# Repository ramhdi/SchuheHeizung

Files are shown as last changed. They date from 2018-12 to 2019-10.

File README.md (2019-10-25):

# SchuheHeizung
DIY Thermostat - Applicable for shoe dryer, sous vide cooker, etc

## Arduino codes
- SchuheHeizung v1: first version, heating controlled by user via Blynk app, microcontroller using NodeMCU
- SchuheHeizung v2: offline heating control, uses OLED display and rotary encoder as user interface, microcontroller using Arduino Nano

## PCB files
- SH v1: first version, microcontroller using NodeMCU, controls DC fan and heater
- SH v2: microcontroller using Arduino Nano, controls AC fan and heater
- SH v3: microcontroller using NodeMCU, controls AC fan and heater

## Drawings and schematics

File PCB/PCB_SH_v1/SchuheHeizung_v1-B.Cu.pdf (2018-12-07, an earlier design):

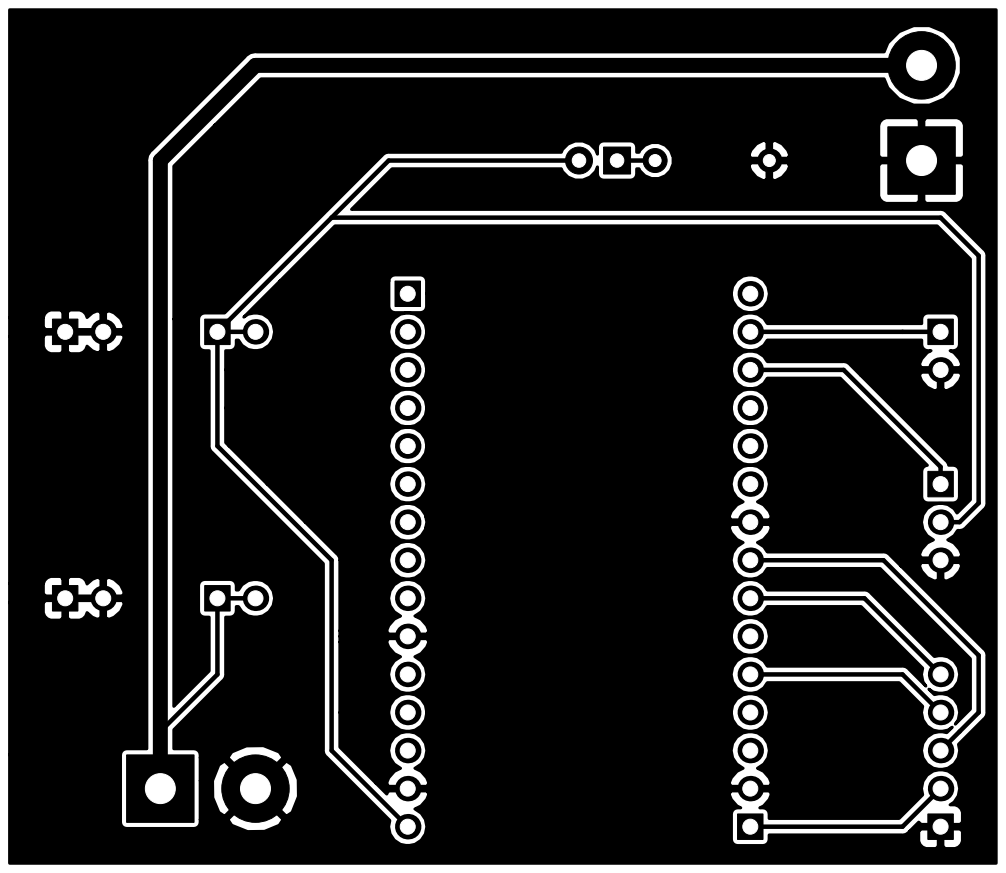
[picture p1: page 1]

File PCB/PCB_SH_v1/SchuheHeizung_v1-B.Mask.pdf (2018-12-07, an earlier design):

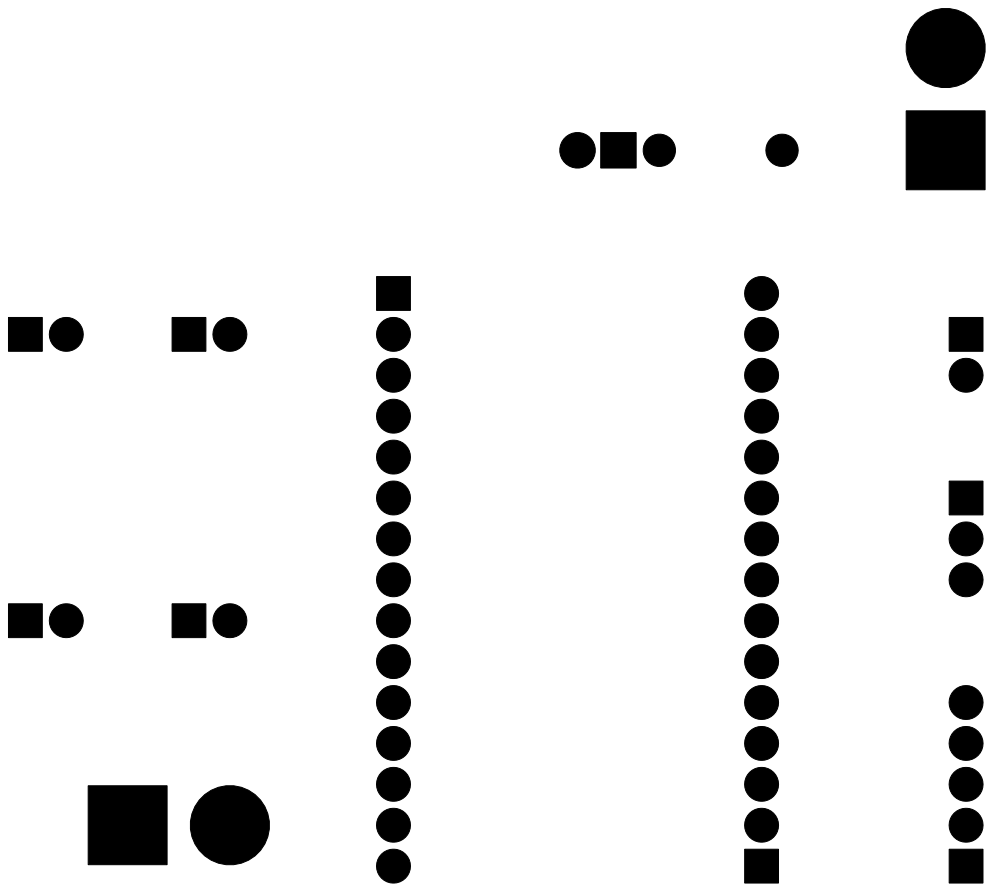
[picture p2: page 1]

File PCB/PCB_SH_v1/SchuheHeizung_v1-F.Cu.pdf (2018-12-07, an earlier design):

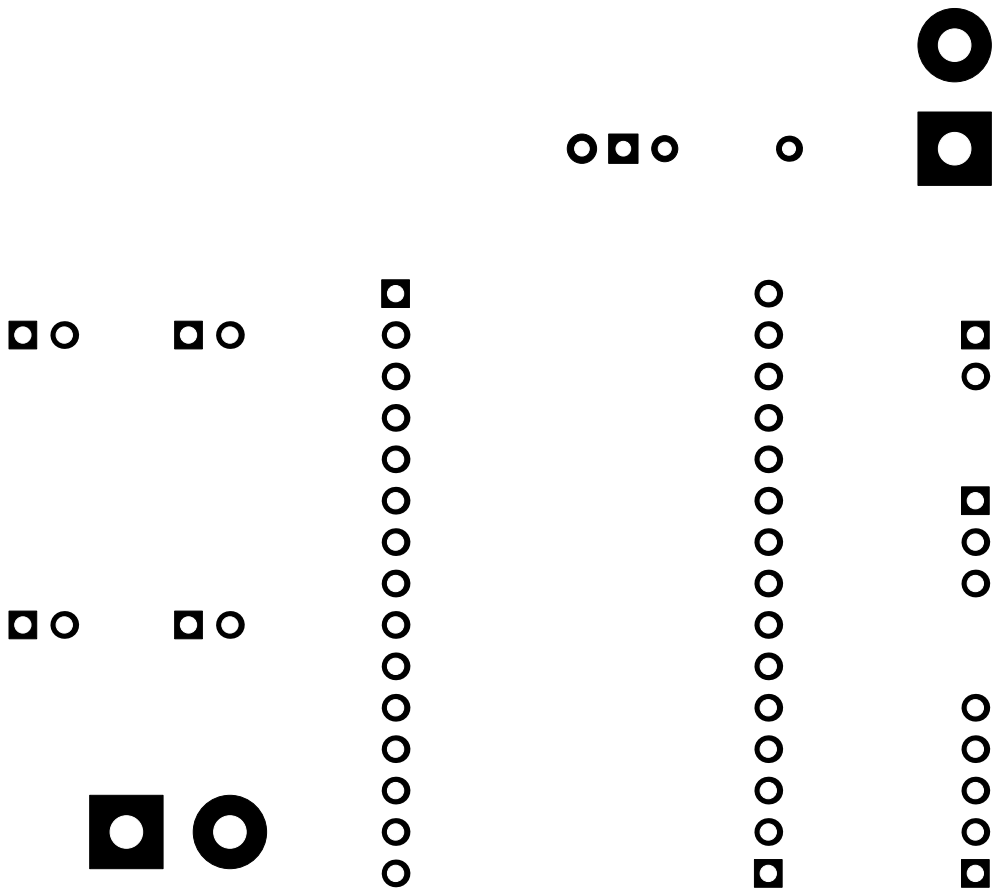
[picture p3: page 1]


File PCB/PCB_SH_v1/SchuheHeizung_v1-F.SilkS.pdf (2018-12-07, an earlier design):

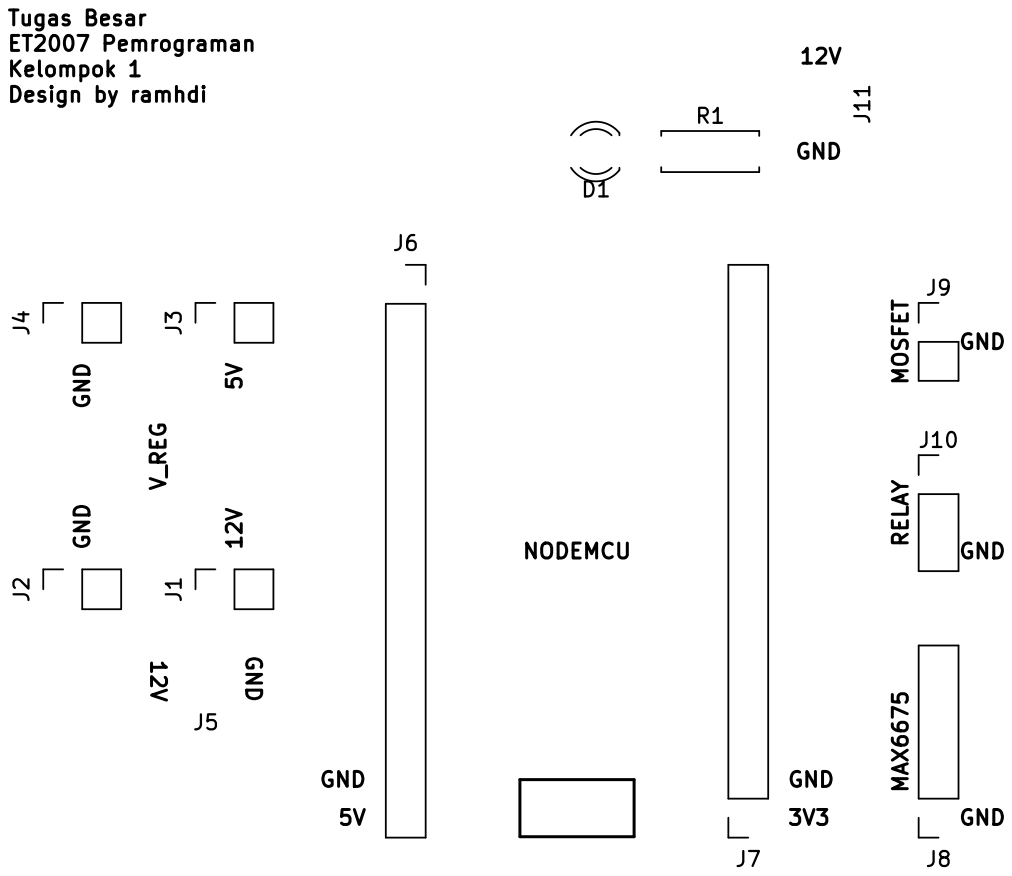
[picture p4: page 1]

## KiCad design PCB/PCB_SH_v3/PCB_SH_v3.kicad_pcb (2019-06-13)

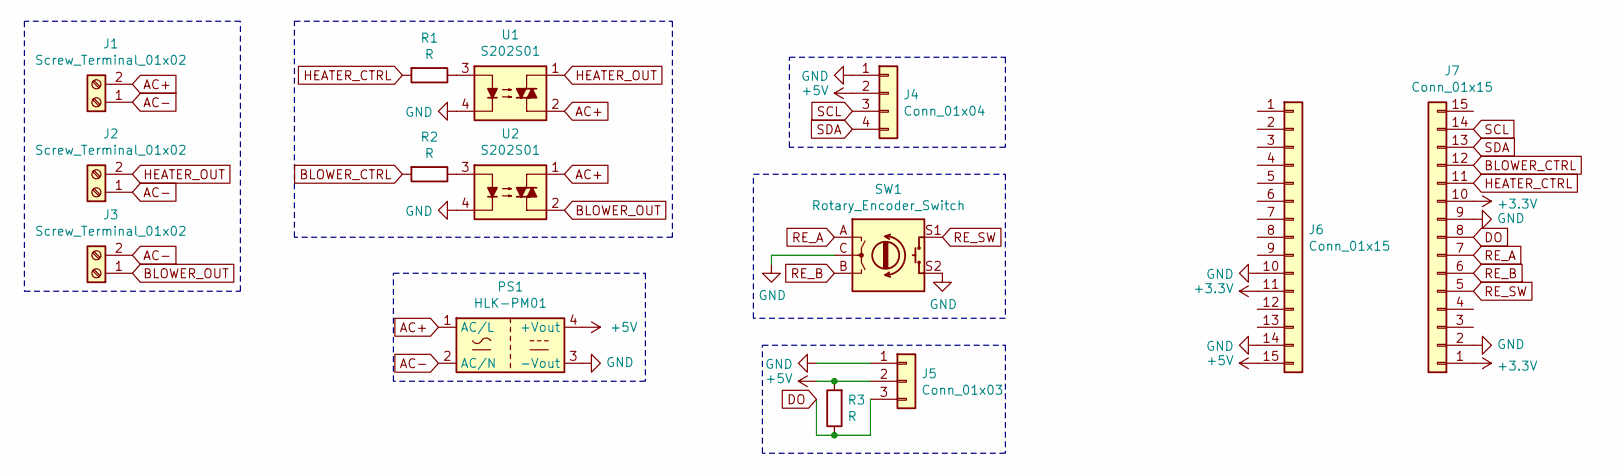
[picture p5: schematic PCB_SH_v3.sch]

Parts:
J1, J2, J3: Screw_Terminal_01x02; TerminalBlock_Wuerth_691311400102_P7.62mm
J4: Conn_01x04; PinSocket_1x04_P2.54mm_Vertical
J5: Conn_01x03; PinSocket_1x03_P2.54mm_Vertical
J6, J7: Conn_01x15; PinSocket_1x15_P2.54mm_Vertical
PS1: HLK-PM01; Converter_ACDC_HiLink_HLK-PMxx
R1, R2, R3: R; R_1206_3216Metric_Pad1.42x1.75mm_HandSolder
SW1: Rotary_Encoder_Switch; RotaryEncoder_Alps_EC11E-Switch_Vertical_H20mm
U1, U2: S202S01; SIP4_Sharp-SSR_P7.62mm_Straight

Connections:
+3V3: J6.11, J7.1, J7.10
+5V: J4.2, J5.2, J6.15, PS1.4 (+Vout), R3.2
AC+: J1.2, PS1.1 (AC/L), U1.2, U2.1
AC-: J1.1, J2.1, J3.2, PS1.2 (AC/N)
BLOWER_CTRL: J7.12, R2.2
BLOWER_OUT: J3.1, U2.2
DO: J5.3, J7.8, R3.1
GND: J4.1, J5.1, J6.10, J6.14, J7.2, J7.9, PS1.3 (-Vout), SW1.C, SW1.S2, U1.4, U2.4
HEATER_CTRL: J7.11, R1.2
HEATER_OUT: J2.2, U1.1
unnamed: R1.1, U1.3
unnamed: R2.1, U2.3
RE_A: J7.7, SW1.A
RE_B: J7.6, SW1.B
RE_SW: J7.5, SW1.S1
SCL: J4.3, J7.14
SDA: J4.4, J7.13

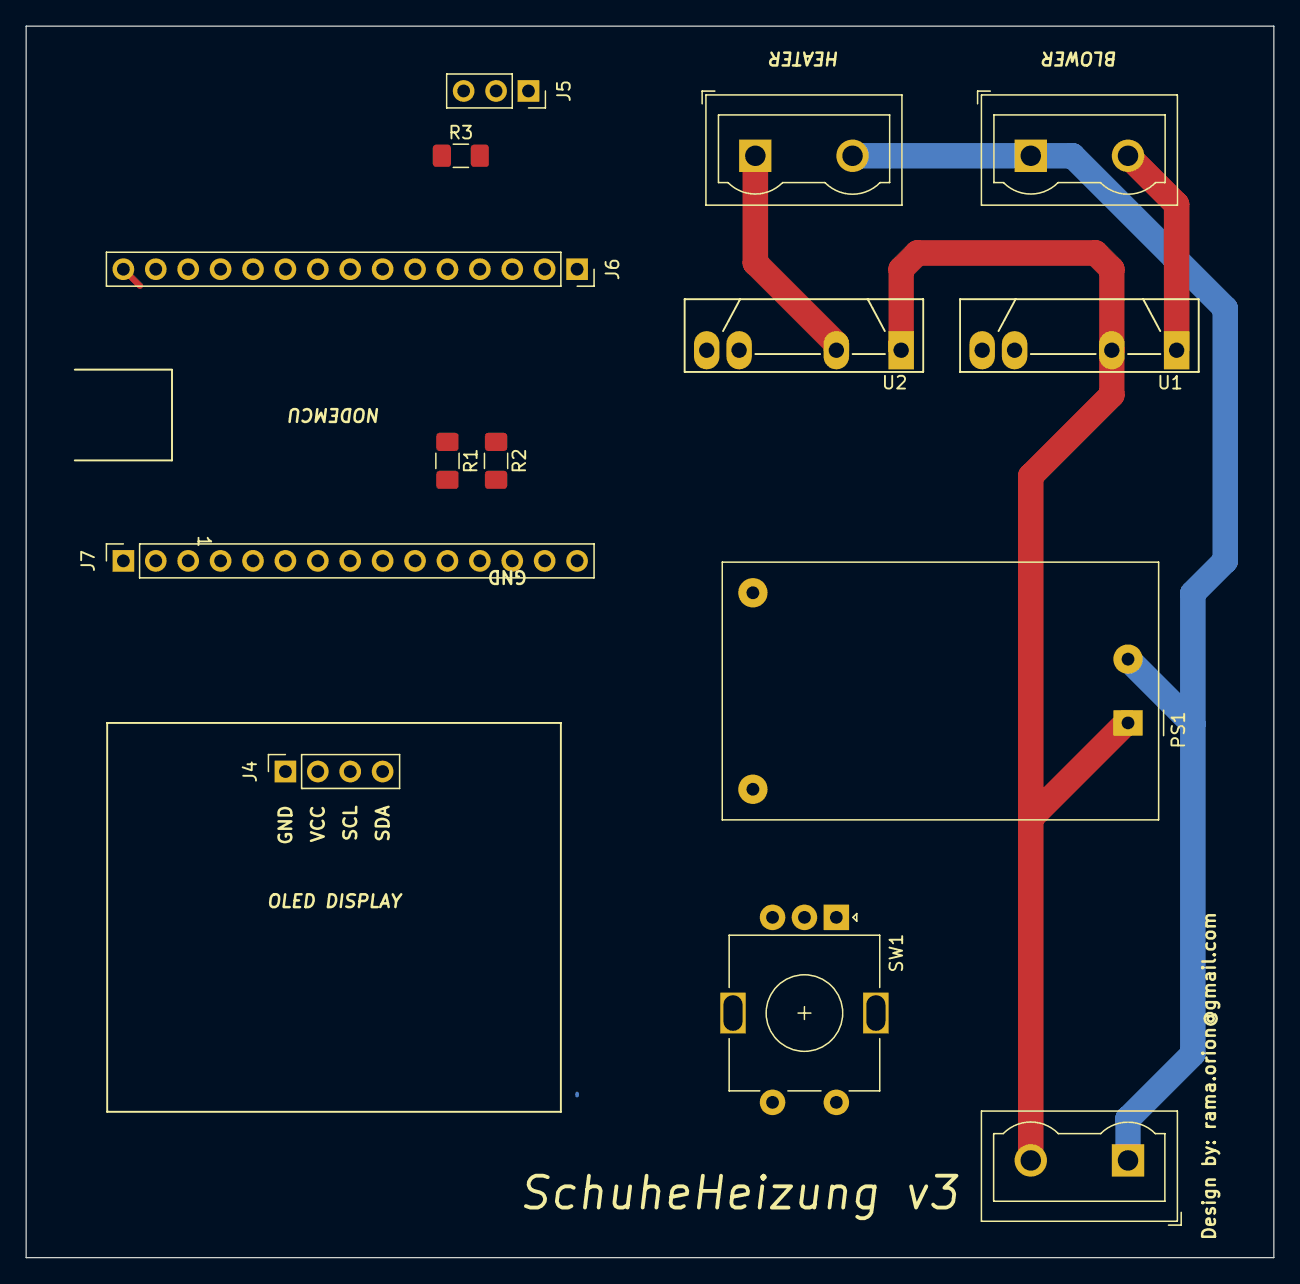
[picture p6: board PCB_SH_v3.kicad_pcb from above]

Board: 2 copper layers, 97.8 x 96.5 mm, 14 parts (0 on the bottom side), 17 nets.

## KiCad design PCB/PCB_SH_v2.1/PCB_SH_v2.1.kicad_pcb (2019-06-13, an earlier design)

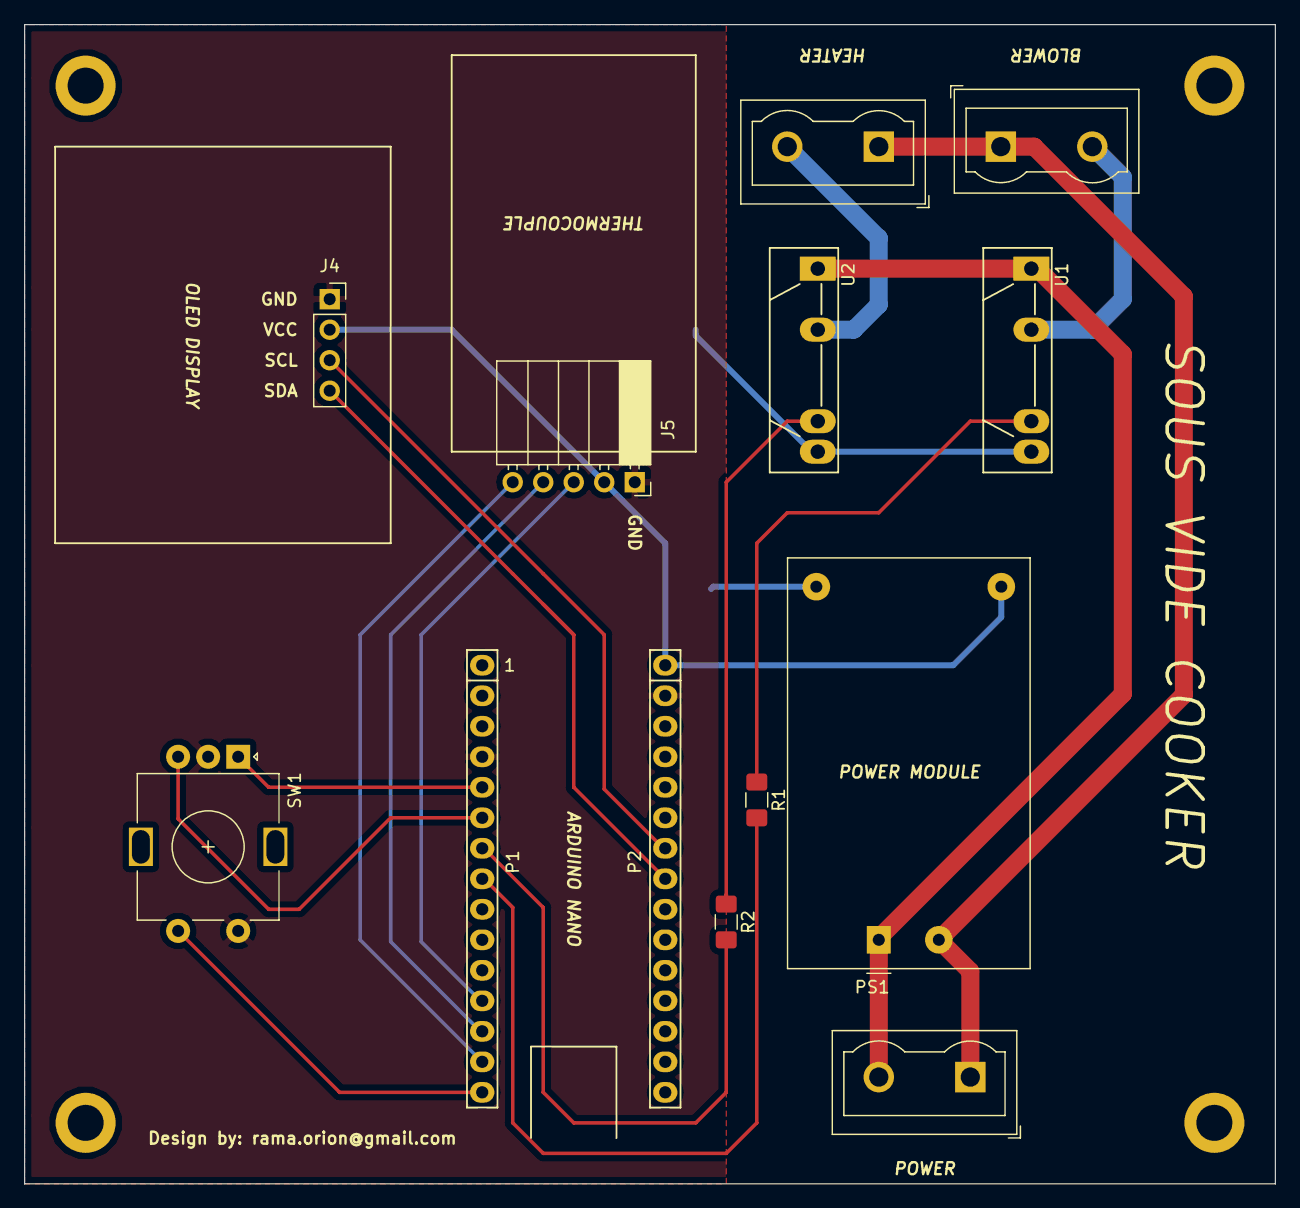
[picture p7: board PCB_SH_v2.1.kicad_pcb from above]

Board: 2 copper layers, 104.1 x 96.5 mm, 13 parts (0 on the bottom side), 19 nets.

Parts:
J1, J2, J3: Screw_Terminal_01x02; TerminalBlock_Wuerth_691311400102_P7.62mm
J4: Conn_01x04; PinSocket_1x04_P2.54mm_Vertical
J5: Conn_01x05; PinSocket_1x05_P2.54mm_Horizontal
P1: Digital; Socket_Strip_Arduino_1x15
P2: Analog; Socket_Strip_Arduino_1x15
PS1: HLK-PM01; Converter_ACDC_HiLink_HLK-PMxx
R1, R2: R; R_1206_3216Metric_Pad1.42x1.75mm_HandSolder
SW1: Rotary_Encoder_Switch; RotaryEncoder_Alps_EC11E-Switch_Vertical_H20mm
U1, U2: S202S01; SIP4_Sharp-SSR_P7.62mm_Straight

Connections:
+5V: J4.2, J5.2, P2.1, PS1.4
/Reset: P1.3, P2.3
AC+: J1.2, PS1.1, U1.1, U2.1
AC-: J1.1, J2.1, J3.1, PS1.2
BLOWER_CTRL: P1.7, R2.2
BLOWER_OUT: J3.2, U2.2
CS: J5.4, P1.13
GND: J4.1, J5.1, P1.4, P2.2, PS1.3, SW1.C, SW1.S2, U1.4, U2.4
HEATER_CTRL: P1.8, R1.2
HEATER_OUT: J2.2, U1.2
unnamed: R1.1, U1.3
unnamed: R2.1, U2.3
RE_A: P1.5, SW1.A
RE_B: P1.6, SW1.B
RE_SW: P1.15, SW1.S1
SCK: J5.3, P1.12
SCL: J4.3, P2.7
SDA: J4.4, P2.8
SO: J5.5, P1.14

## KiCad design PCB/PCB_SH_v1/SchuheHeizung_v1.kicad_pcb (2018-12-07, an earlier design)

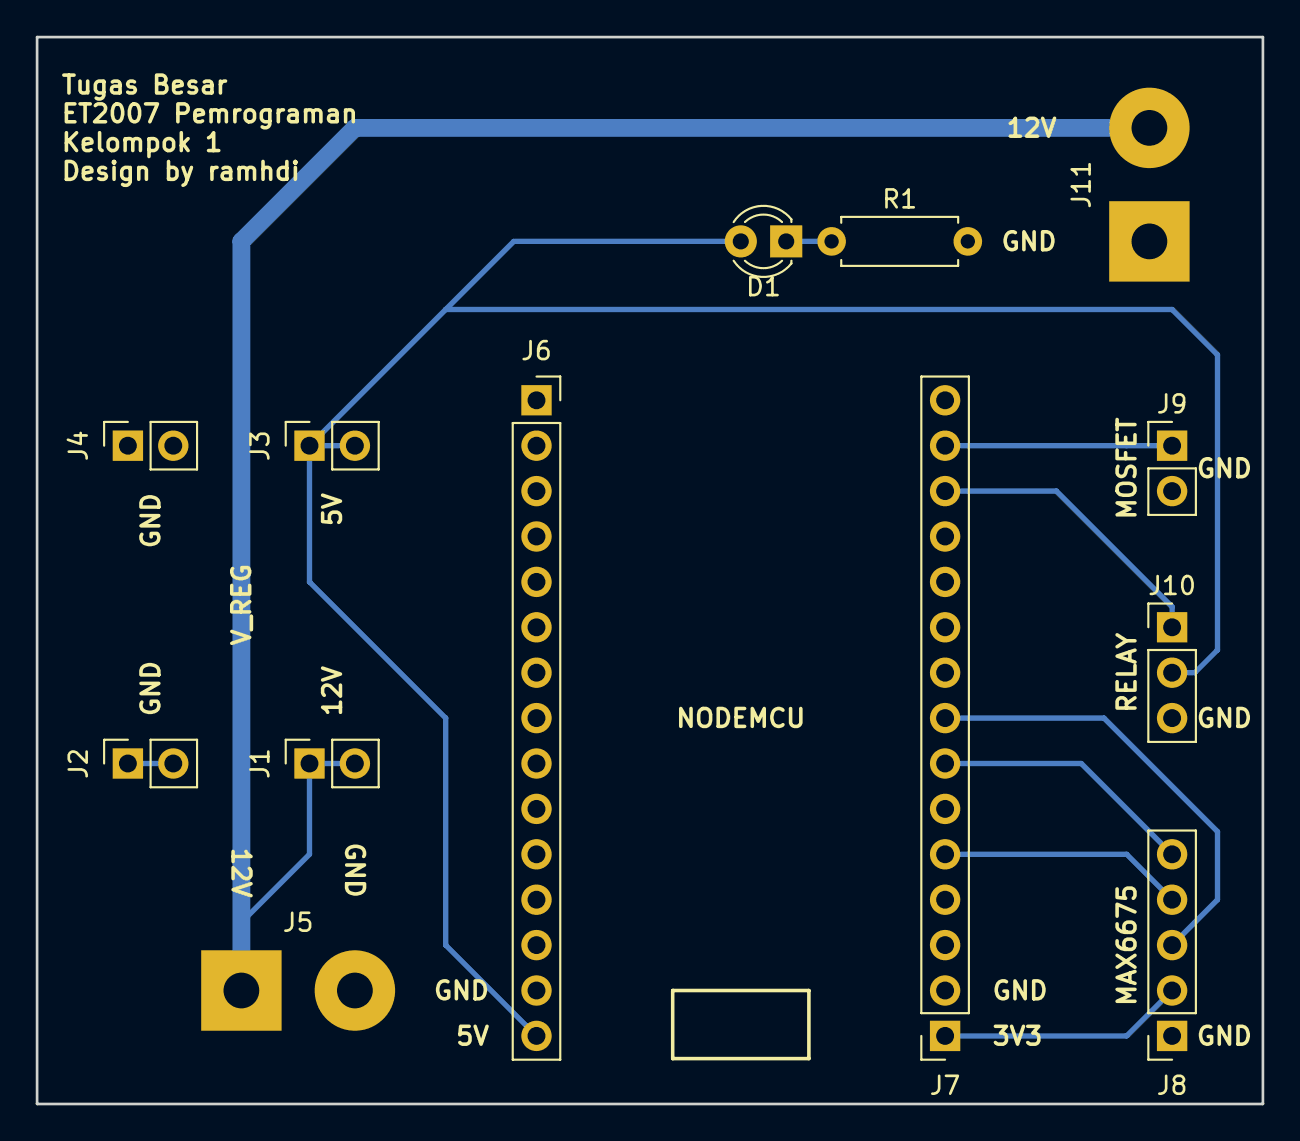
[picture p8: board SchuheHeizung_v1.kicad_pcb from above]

Board: 2 copper layers, 68.6 x 59.7 mm, 13 parts (0 on the bottom side), 10 nets.

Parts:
D1: LED; LED_D3.0mm
J1, J2, J3, J4: Conn_01x02_Female; PinSocket_1x02_P2.54mm_Vertical
J5, J11: Screw_Terminal_01x02; SolderWirePad_1x02_P7.62mm_Drill2mm
J6, J7: Conn_01x15_Female; PinSocket_1x15_P2.54mm_Vertical
J8: Conn_01x05_Female; PinSocket_1x05_P2.54mm_Vertical
J9: Conn_01x02_Male; PinHeader_1x02_P2.54mm_Vertical
J10: Conn_01x03_Male; PinHeader_1x03_P2.54mm_Vertical
R1: 220; R_Axial_DIN0207_L6.3mm_D2.5mm_P7.62mm_Horizontal

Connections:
+3V3: J6.11, J7.1, J7.10, J8.2
+5V: D1.2, J3.1, J3.2, J6.15, J10.2
+12V: J1.1, J1.2, J5.1, J11.2
CS: J7.5, J8.4
GND: J2.1, J2.2, J4.1, J4.2, J5.2, J6.10, J6.14, J7.2, J7.9, J8.1, J9.2, J10.3, J11.1, R1.2
MOSFET: J7.14, J9.1
unnamed: D1.1, R1.1
RELAY: J7.13, J10.1
SCK: J7.8, J8.3
SO: J7.7, J8.5

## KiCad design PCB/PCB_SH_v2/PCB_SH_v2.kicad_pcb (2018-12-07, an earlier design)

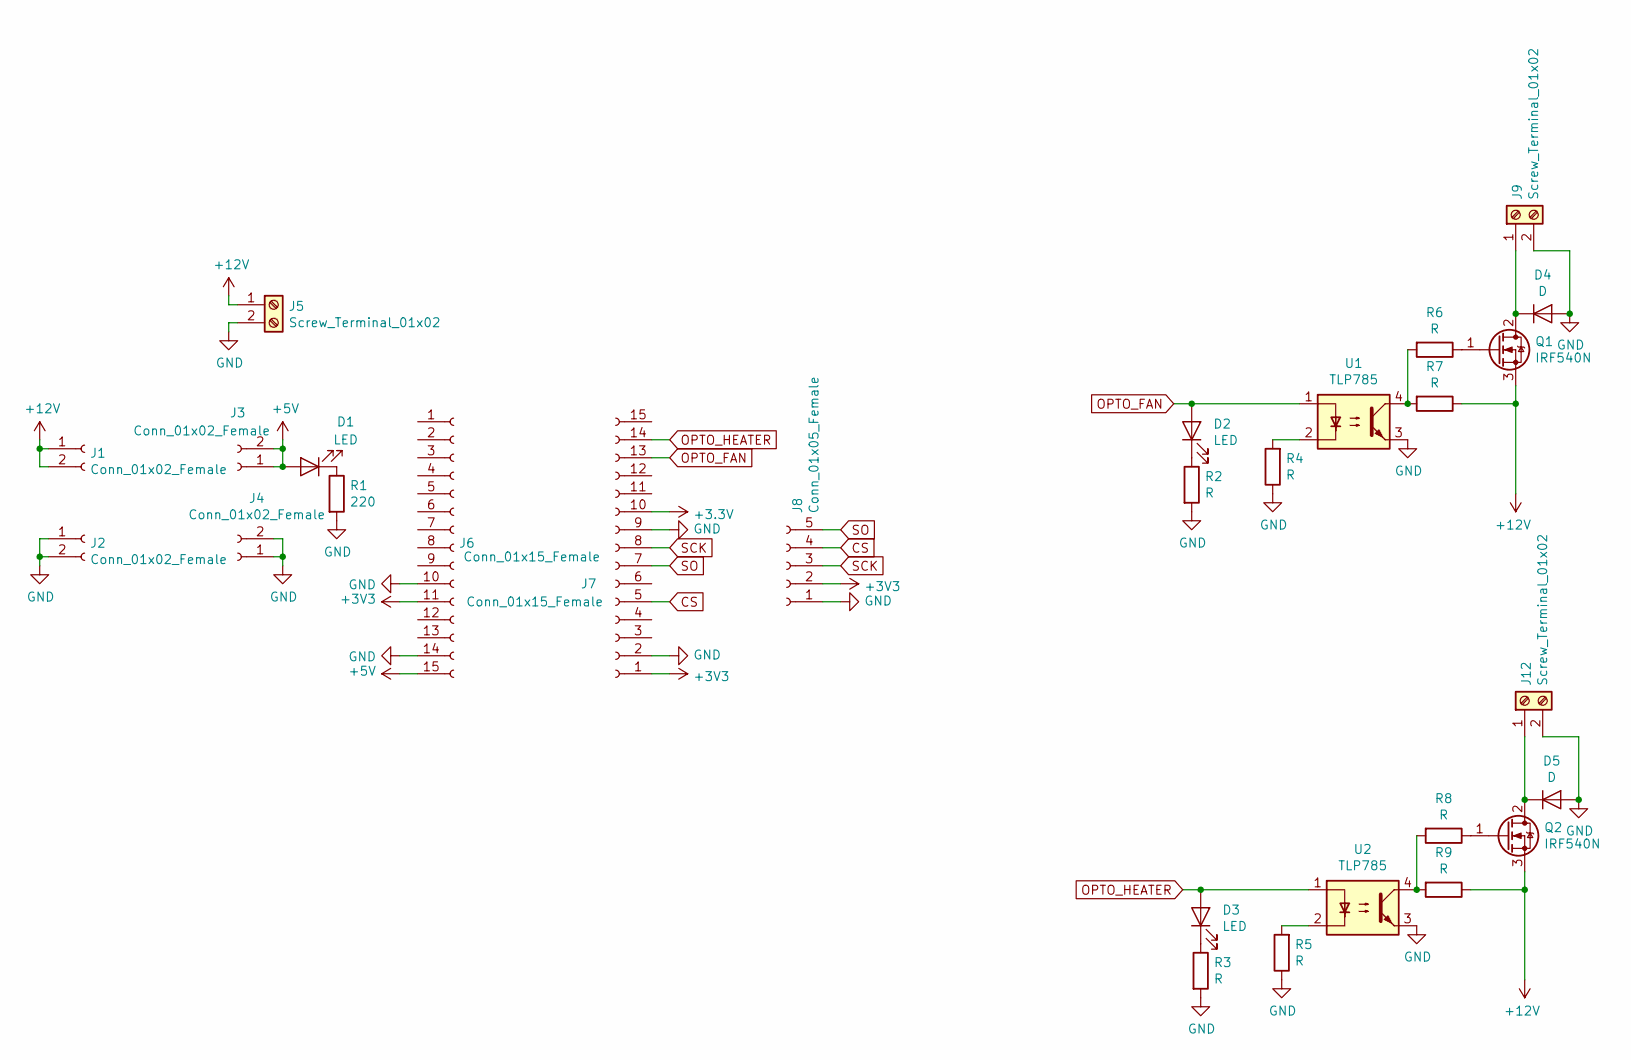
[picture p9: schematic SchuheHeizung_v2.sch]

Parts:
D1, D2, D3: LED; LED_1206_3216Metric_Pad1.42x1.75mm_HandSolder
D4, D5: D; D_1206_3216Metric_Pad1.42x1.75mm_HandSolder
J1, J2, J3, J4: Conn_01x02_Female; PinSocket_1x02_P2.54mm_Vertical
J5, J9, J12: Screw_Terminal_01x02; SolderWirePad_1x02_P7.62mm_Drill2mm
J6, J7: Conn_01x15_Female; PinSocket_1x15_P2.54mm_Vertical
J8: Conn_01x05_Female; PinSocket_1x05_P2.54mm_Vertical
Q1, Q2: IRF540N; TO-263-2
R1: 220; R_1206_3216Metric_Pad1.42x1.75mm_HandSolder
R2, R3, R4, R5, R6, R7, R8, R9: R; R_1206_3216Metric_Pad1.42x1.75mm_HandSolder
U1, U2: TLP785; DIP-4_W7.62mm

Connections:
+5V: D1.2 (A), J3.1, J3.2, J6.15
+12V: J1.1, J1.2, J5.1, Q1.3 (S), Q2.3 (S), R7.1, R9.1
CS: J7.5, J8.4
GND: D4.2 (A), D5.2 (A), J2.1, J2.2, J4.1, J4.2, J5.2, J6.10, J6.14, J7.2, J7.9, J8.1, J9.2, J12.2, R1.2, R2.2, R3.2, R4.1, R5.1, U1.3, U2.3
unnamed: D1.1 (K), R1.1
unnamed: D2.1 (K), R2.1
unnamed: D3.1 (K), R3.1
unnamed: D4.1 (K), J9.1, Q1.2 (D)
unnamed: D5.1 (K), J12.1, Q2.2 (D)
unnamed: Q1.1 (G), R6.1
unnamed: Q2.1 (G), R8.1
unnamed: R4.2, U1.2
unnamed: R5.2, U2.2
unnamed: R6.2, R7.2, U1.4
unnamed: R8.2, R9.2, U2.4
OPTO_FAN: D2.2 (A), J7.13, U1.1
OPTO_HEATER: D3.2 (A), J7.14, U2.1
SCK: J7.8, J8.3
SO: J7.7, J8.5

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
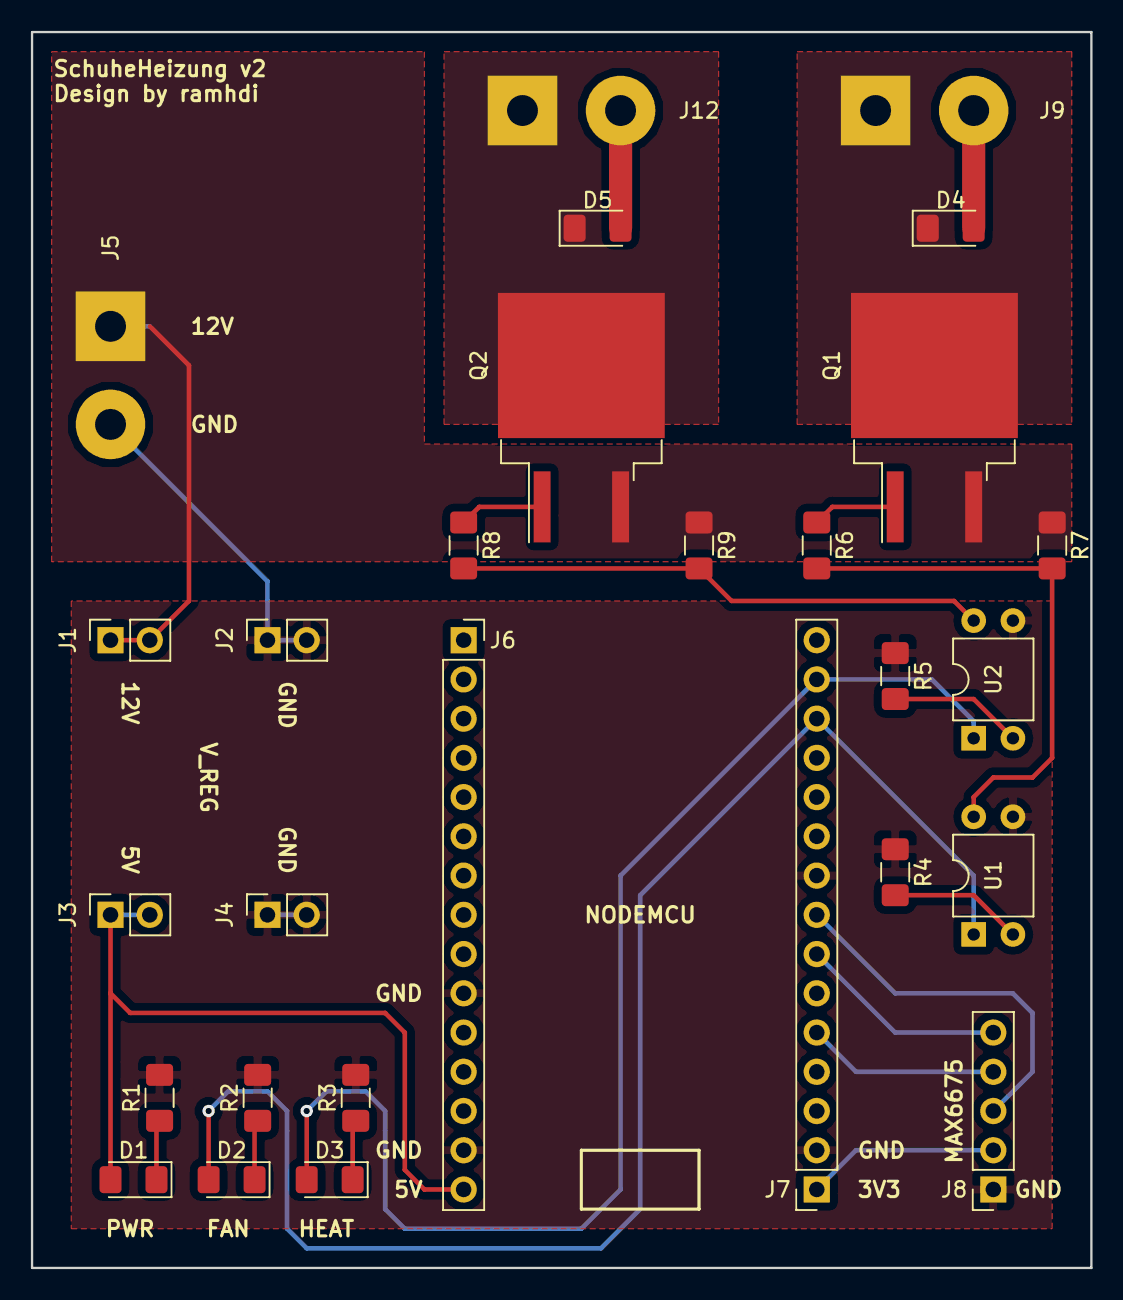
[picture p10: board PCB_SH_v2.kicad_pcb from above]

Board: 2 copper layers, 68.6 x 80.0 mm, 28 parts (0 on the bottom side), 20 nets.

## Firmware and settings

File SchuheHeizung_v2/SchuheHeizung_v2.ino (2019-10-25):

/*
  Low-cost Sous vide Cooker
  version 1.0
  Using libraries:
  - Adafruit SSD1306 for OLED display - learn.adafruit.com
  - Rotary encoder switch - www.belajarduino.com
*/

#include <SPI.h>
#include <Wire.h>
#include <Adafruit_GFX.h>
#include <Adafruit_SSD1306.h>
#include "max6675.h"

#define DEBUG
#define SCREEN_WIDTH 128 // OLED display width, in pixels
#define SCREEN_HEIGHT 64 // OLED display height, in pixels

// Declaration for an SSD1306 display connected to I2C (SDA, SCL pins)
#define OLED_RESET     -1 // Reset pin # (or -1 if sharing Arduino reset pin)
Adafruit_SSD1306 display(SCREEN_WIDTH, SCREEN_HEIGHT, &Wire, OLED_RESET);

int SCK_PIN = 9;
int CS_PIN = 10;
int SO_PIN = 11;
MAX6675 thermocouple(SCK_PIN, CS_PIN, SO_PIN);

int mode;
const int REQ_TEMPERATURE = 0;
const int REQ_DURATION = 1;
const int PREHEATING = 2;
const int HEATING = 3;

int HEATER_PIN = 4;
int BLOWER_PIN = 5;

int out_a = 2;
int out_b = 3;
int sw = 12;

volatile int lastEncoded = 0;
volatile long encoderValue = 0;
long lastencoderValue = 0;
int lastMSB = 0;
int lastLSB = 0;

double temp_desired, temp_sensor;
unsigned long time_start, time_now, duration;

int swState = LOW;
long lastDebounceTime = 0;
long debounceDelay = 50;
unsigned long previousMillisControl = 0;
unsigned long previousMillisReadTemp = 0;


void setup() {
#ifdef DEBUG
  Serial.begin(9600);
#endif
  // SSD1306_SWITCHCAPVCC = generate display voltage from 3.3V internally
  if (!display.begin(SSD1306_SWITCHCAPVCC, 0x3C)) { // Address 0x3D for 128x64
#ifdef DEBUG
    Serial.println(F("SSD1306 allocation failed"));
#endif
    for (;;); // Don't proceed, loop forever
  }

  // Show initial display buffer contents on the screen --
  // the library initializes this with an Adafruit splash screen.
  display.display();
  delay(2000); // Pause for 2 seconds

  // Clear the buffer
  display.clearDisplay();

  pinMode(HEATER_PIN, OUTPUT);
  pinMode(BLOWER_PIN, OUTPUT);
  digitalWrite(HEATER_PIN, LOW);
  digitalWrite(BLOWER_PIN, LOW);

  pinMode(out_a, INPUT_PULLUP);
  pinMode(out_b, INPUT_PULLUP);
  pinMode(sw, INPUT_PULLUP);
  attachInterrupt(0, updateEncoder, CHANGE);
  attachInterrupt(1, updateEncoder, CHANGE);

  mode = REQ_TEMPERATURE;
#ifdef DEBUG
  Serial.println(F("====================================="));
  Serial.println(F("===== Low-cost Sous Vide Cooker ====="));
  Serial.println(F("====================================="));
#endif
}


void loop() {
  if (mode == REQ_TEMPERATURE) {
    // requesting temperature to user
    display.clearDisplay();
    display.setTextSize(2);
    display.setTextColor(WHITE);
    display.setCursor(0, 0);
    display.print("Suhu (C):");

    temp_desired = 30 + encoderValue;
#ifdef DEBUG
    Serial.print(F("User wants temperature at ")); Serial.println(temp_desired);
#endif
    display.setCursor(0, 31);
    display.print((int)temp_desired);
    swState = digitalRead(sw);
    //Serial.print(swState);
    if (swState == LOW) {
      mode = REQ_DURATION;

      encoderValue = 0;
    }

    //Serial.println(mode);
    display.display();
    delay(250);
  }

  else if (mode == REQ_DURATION) {
    // requesting duration to user
    display.clearDisplay();
    display.setTextSize(2);
    display.setTextColor(WHITE);
    display.setCursor(0, 0);
    display.print("Durasi");
    display.setCursor(0, 20);
    display.print("(menit):");

    unsigned long duration_mins = 10 + encoderValue;
    display.setCursor(0, 40);
    display.print(duration_mins);
#ifdef DEBUG
    Serial.print(F("User wants duration at ")); Serial.println(duration_mins);
#endif
    swState = digitalRead(sw);
    //Serial.print(swState);
    if (swState == LOW) {
      duration = duration_mins * 60 * 1000;
      time_start = millis();
#ifdef DEBUG
      Serial.println(duration);
      Serial.println(time_start);
#endif
      digitalWrite(BLOWER_PIN, HIGH);

      encoderValue = 0;
      mode = PREHEATING;
    }
    //Serial.println(mode);
    display.display();
    delay(250);
  }

  else if (mode == PREHEATING) {
    // preheating (waiting for the heater to reach target temperature)
    time_now = millis();
    swState = digitalRead(sw);

    // read temperature
    unsigned long currentMillisReadTemp = millis();
    if (currentMillisReadTemp - previousMillisReadTemp >= 1000) {
      previousMillisReadTemp = currentMillisReadTemp;
      temp_sensor = thermocouple.readCelsius();
    }
#ifdef DEBUG
    Serial.println(temp_sensor);
#endif
    if ((time_now - time_start > duration) || !swState) {
      display.clearDisplay();
      display.setTextSize(2);
      display.setCursor(0, 0);
      display.print("Finished");
#ifdef DEBUG
      Serial.println(F("Finished cooking!"));
#endif
      digitalWrite(BLOWER_PIN, LOW);
      digitalWrite(HEATER_PIN, LOW);
      display.display();
      delay(2000);
      mode = REQ_TEMPERATURE;
    } else {
      String templeft = String((int)temp_sensor) + " -> " + String((int)temp_desired);
      display.clearDisplay();
      display.setTextSize(2);
      display.setCursor(0, 0);
      display.print("Preheating");
      display.setCursor(0, 20);
      display.print(templeft);

      // waiting for the heater to reach target temperature
      if (temp_sensor < temp_desired) {
        digitalWrite(HEATER_PIN, HIGH);
      } else {
        // switch mode to heating
        digitalWrite(HEATER_PIN, LOW);
        mode = HEATING;
      }
    }
    display.display();
  }

  else if (mode == HEATING) {
    // heating
    time_now = millis();
    swState = digitalRead(sw);

    // read temperature
    unsigned long currentMillisReadTemp = millis();
    if (currentMillisReadTemp - previousMillisReadTemp >= 1000) {
      previousMillisReadTemp = currentMillisReadTemp;
      temp_sensor = thermocouple.readCelsius();
    }
#ifdef DEBUG
    Serial.println(temp_sensor);
#endif
    if ((time_now - time_start > duration) || !swState) {
      display.clearDisplay();
      display.setTextSize(2);
      display.setCursor(0, 0);
      display.print("Finished");
#ifdef DEBUG
      Serial.println(F("Finished cooking!"));
#endif
      digitalWrite(BLOWER_PIN, LOW);
      digitalWrite(HEATER_PIN, LOW);
      display.display();
      delay(2000);
      mode = REQ_TEMPERATURE;
    } else {
      // control heater and display
      unsigned long currentMillisControl = millis();
      if (currentMillisControl - previousMillisControl >= 100) {
        previousMillisControl = currentMillisControl;
        unsigned long time_left = (duration - (time_now - time_start)) / 1000;
        unsigned int time_left_hrs = time_left / 3600;
        unsigned int time_left_mins = (time_left / 60) % 60;
        unsigned int time_left_secs = time_left % 60;

        String templeft = String((int)temp_sensor) + " -> " + String((int)temp_desired);
        String timeleft = "";
        if (time_left_hrs != 0) {
          timeleft += String(time_left_hrs);
          timeleft += "j ";
        }

        if (time_left_mins != 0 || time_left_hrs != 0) {
          timeleft += String(time_left_mins);
          timeleft += "m ";
        }
        timeleft += String(time_left_secs); timeleft += "d";
        display.clearDisplay();
        display.setTextSize(2);
        display.setCursor(0, 0);
        display.print(timeleft);
        display.setCursor(0, 20);
        display.print(templeft);
#ifdef DEBUG
        Serial.println(timeleft);
#endif
        if (temp_sensor < temp_desired) {
          digitalWrite(HEATER_PIN, HIGH);
        } else {
          digitalWrite(HEATER_PIN, LOW);
        }
      }
    }
    display.display();
  }
}

void updateEncoder() {
  int MSB = digitalRead(out_a); //MSB = most significant bit
  int LSB = digitalRead(out_b); //LSB = least significant bit

  int encoded = (MSB << 1) | LSB; //converting the 2 pin value to single number
  int sum  = (lastEncoded << 2) | encoded; //adding it to the previous encoded value

  if (sum == 0b1101) encoderValue++;
  if (sum == 0b1110) encoderValue--;

  lastEncoded = encoded; //store this value for next time
}

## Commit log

2018-12-07 Added future version
    [SchuheHeizung_v1.kicad_pcb, SchuheHeizung_v1.sch, SchuheHeizung_v2.kicad_pcb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]
2019-06-13 Reorganized repo
    [SchuheHeizung_v1.kicad_pcb, SchuheHeizung_v1.sch, SchuheHeizung_v2.kicad_pcb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]
2019-06-13 New PCB v3 files
    [PCB_SH_v2.1.kicad_pcb, PCB_SH_v2.1.sch, PCB_SH_v2.kicad_pcb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]
